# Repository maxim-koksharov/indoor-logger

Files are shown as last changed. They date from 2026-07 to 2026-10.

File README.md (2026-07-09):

# Air Quality Monitor — ESP8266 RTOS SDK

ESP8266-based indoor air quality monitoring system with OLED display, ENS160+AHT21 sensors, WiFi data sync, and a web dashboard.

## System Overview

Two ESP8266 devices communicating over WiFi (both connect to your home router):

```
┌────────────────────┐      WiFi (STA)       ┌────────────────────┐
│   Server (16MB)    │◄─────────────────────►│   Client (4MB)     │
│                    │    Your Home Router   │                    │
│  STA mode          │      192.168.x.x      │  STA mode          │
│  HTTP REST API     │                       │  OLED Display      │
│  Web Dashboard     │                       │  ENS160 + AHT21    │
│  Data Aggregation  │                       │  Local SPIFFS      │
│  UDP discovery     │                       │  WiFi sync         │
│  Backup WiFi       │                       │  UDP discovery     │
│  Timezone config   │                       │  Fallback SERVER_IP│
└────────────────────┘                       └────────────────────┘
```

**WiFi Mode:**
- **Server**: STA-only (connects to your router). Supports primary + backup SSID.
- **Client**: STA-only (connects to the same router). Discovers server via UDP broadcast.

**Server Discovery:** Client sends UDP broadcast to port 5000. Server responds with its IP. No static IP needed.

## Hardware Requirements

- 2× Wemos D1 Mini (ESP8266EX) — 4MB flash for the client, 16MB for the server
- 1× ENS160 + AHT21 air quality sensor module (I2C)
- 1× 0.91" SSD1306 OLED display 128×32 (I2C)
- 1× Tactile button (optional, GPIO12)
- Breadboard and jumper wires

### Wiring

All three I2C devices share a single bus (bus 0):

| Wemos Pin | GPIO | Connection |
|---|---|---|
| D1 | GPIO5 | I2C SCL (OLED + ENS160 + AHT21) |
| D2 | GPIO4 | I2C SDA (OLED + ENS160 + AHT21) |
| D5 | GPIO14 | Output LOW (button GND) |
| D6 | GPIO12 | Input pull-up (button sense) |
| 3V3 | — | VCC (all modules) |
| GND | — | GND (all modules) |

| Device | I2C Address |
|---|---|
| SSD1306 OLED | `0x3C` |
| ENS160 | `0x53` |
| AHT21 | `0x38` |

## Build System

The project uses the standard ESP-IDF CMake build system.
**SDK**: ESP8266 RTOS SDK v3.4 (`/esp/ESP8266_RTOS_SDK`)
**Toolchain**: `/esp/bin/xtensa-lx106-elf/bin`

All commands run inside the Docker container (see `AGENTS.md` for build/run instructions).

### Menuconfig (one-time setup)

```bash
# Client: Client ID, WiFi SSID/pass
idf.py -C apps/client menuconfig

# Server: WiFi SSID/pass (primary + backup)
idf.py -C apps/server menuconfig
```

### Build

```bash
idf.py -C apps/client build
idf.py -C apps/server build
```

### Flash

```bash
idf.py -C apps/client -p /dev/ttyUSB0 flash
idf.py -C apps/server -p /dev/ttyUSB1 flash
```

### Clean

```bash
idf.py -C apps/client fullclean
idf.py -C apps/server fullclean
```

> For the full command list, including monitor and erase, see `AGENTS.md`.

## WiFi Configuration

WiFi SSID and password are read from `/workspace/wifi.env` at build time. Create the file (it is gitignored):

```bash
cat > /workspace/wifi.env <<EOF
WIFI_SSID=MyHomeWiFi
WIFI_PASS=MyPassword
SERVER_IP=192.168.1.100
EOF
```

`SERVER_IP` is optional. It is used by the client as a fallback when UDP broadcast discovery is blocked by the router.

You can still override credentials via `menuconfig` or NVS if needed.

### Server

```bash
idf.py -C apps/server menuconfig
# Server Configuration → Primary WiFi SSID & Password
#                      → Backup WiFi SSID & Password (optional)
idf.py -C apps/server build
idf.py -C apps/server -p /dev/ttyUSB1 flash
```

**Operating mode:**
- The server connects to your router (STA mode)
- Supports a primary and a backup WiFi network (switches after 3 failed attempts)
- Runs a UDP discovery service on port 5000
- The client finds the server automatically via UDP broadcast
- When the network is unreachable → retries connection every 60 sec
- On wrong password → retries every 60 min

**NVS (alternative to menuconfig):**
Credentials can be stored in NVS (survives reflash):
```c
// Via provisioning or a debug script:
nvs_set_str("wifi", "sta_ssid", "YourNetwork");
nvs_set_str("wifi", "sta_pass", "YourPassword");
nvs_commit();
```
NVS takes precedence over menuconfig.

### Client

```bash
idf.py -C apps/client menuconfig
# Client Configuration → Client device identifier
#                      → WiFi SSID (same as server)
#                      → WiFi password (same as server)
idf.py -C apps/client build
idf.py -C apps/client -p /dev/ttyUSB0 flash
```

**Operating mode:**
- The client connects to the same router (STA mode)
- Sends a UDP broadcast on port 5000 to discover the server
- Automatically uses the IP returned by the server for data uploads
- Falls back to `SERVER_IP` from `wifi.env` if broadcast discovery is blocked
- Runs a state machine:
  - `DISCOVERING` — connect to WiFi, discover server
  - `CONNECTED` — upload records, apply server config, sleep for sync interval
  - `AUTONOMOUS` — keep reading sensors locally, retry discovery every hour

### What is `menuconfig` and why do I need it?

`idf.py menuconfig` opens a text-based project configuration UI.
It lets you change build parameters without editing source files:

**WiFi credentials** are read from `wifi.env` at build time. Use `menuconfig` only if you want to override them or store them in the firmware image directly.

**For the client** (`Client Configuration`):
- `Client device identifier` — unique device ID (default `test_client`).
  Used as `?id=<client_id>` when uploading to the server.
- `Display timeout` — auto-off timeout in seconds (0 = always on).
- `Discovery timeout / retry interval / default sync interval` — discovery and sync behavior.

Changes are saved in `sdkconfig` and applied on `idf.py build`.
The config options are exposed in code as `CONFIG_CLIENT_ID`, etc.

**Display:** Off by default. Turns on for 6 seconds on a button press
(2 screens × 3 seconds: temp/time → CO₂/VOC/AQI).

### Serial Monitor

`idf.py monitor` does not work inside Docker (termios error).
Use this Python script instead:

```bash
python3 -c "
import serial, time
ser = serial.Serial('/dev/ttyUSB0', 74880, timeout=1)
ser.dtr = False; ser.rts = True; time.sleep(0.1); ser.rts = False; time.sleep(2)
buf = b''; deadline = time.time() + 10
while time.time() < deadline:
    data = ser.read(4096)
    if data: buf += data
    elif len(buf) > 0: break
ser.close(); print(buf.decode('utf-8', errors='replace'))
"
```

## USB Connection & Serial Debug

Both ESP8266 boards are connected to the host via USB and are passed through to the
container by `docker compose.yml`. All build, flash, and serial debug commands
work **from inside the container** — there is no need to switch to the host shell.

### Device Mapping

| Host device | Board | Used for |
|---|---|---|
| `/dev/ttyUSB0` | Client (Wemos D1 Mini + OLED + ENS160 + AHT21) | Flash, monitor, debug |
| `/dev/ttyUSB1` | Server (Wemos D1 Mini, 16MB flash) | Flash, monitor, debug |

The container is configured with:
- `devices:` passing `/dev/ttyUSB0` and `/dev/ttyUSB1` through
- `device_cgroup_rules: c 188:* rmw` to allow `esptool` / `idf.py` to manage them
- `group_add: ["20"]` (the `dialout` group on the host) so the in-container `dev` user
  can read/write serial ports without `sudo`

### Verifying the connection

Open a shell in the container and check that the devices are visible:

```bash
docker compose run --rm bash

# Inside the container:
ls -l /dev/ttyUSB*
# crw-rw---- 1 root dialout 188, 0 ... /dev/ttyUSB0
# crw-rw---- 1 root dialout 188, 1 ... /dev/ttyUSB1

lsusb
# Bus 001 Device 005: ID 1a86:7523 QinHeng Electronics CH340 serial converter
# ...

# Confirm the in-container user is in dialout:
id
# uid=1000(dev) gid=1000(dev) groups=1000(dev),20(dialout)
```

If `/dev/ttyUSB*` are missing, the host likely does not have permission or the
devices are not enumerated yet:

```bash
# On the host:
ls -l /dev/ttyUSB*              # check device presence
sudo usermod -aG dialout $USER  # add your user to dialout (one-time)
# then log out / log in
```

### Tailing serial output (one-shot, 10s)

Capture the boot log without leaving the container:

```bash
docker compose run --rm bash -c '
  python3 -c "
import serial, time
ser = serial.Serial(\"/dev/ttyUSB0\", 74880, timeout=1)
ser.dtr = False; ser.rts = True; time.sleep(0.1); ser.rts = False; time.sleep(2)
buf = b\"\"; deadline = time.time() + 10
while time.time() < deadline:
    data = ser.read(4096)
    if data: buf += data
    elif len(buf) > 0: break
ser.close(); print(buf.decode(\"utf-8\", errors=\"replace\"))
"
'
```

For the server, replace `/dev/ttyUSB0` with `/dev/ttyUSB1`.

### Continuous log tail (interactive)

For long-running debug sessions, keep the port open and follow output:

```bash
docker compose run --rm bash

# Inside the container:
stty -F /dev/ttyUSB0 74880 raw -echo
cat /dev/ttyUSB0
# press RST on the board to see fresh boot logs
# Ctrl-C to exit
```

### Flashing a board

Flash commands work the same as on the host — just run them from inside the container:

```bash
docker compose run --rm bash

# Inside the container:
cd /workspace/apps/client
idf.py -p /dev/ttyUSB0 flash

cd /workspace/apps/server
idf.py -p /dev/ttyUSB1 flash
```

### Troubleshooting

| Symptom | Likely cause | Fix |
|---|---|---|
| `Could not open /dev/ttyUSB0` | Device busy or not present | Unplug/replug the USB cable; check `lsusb` on the host |
| `Permission denied` on `/dev/ttyUSB*` | User not in `dialout` | `sudo usermod -aG dialout $USER` on the host, then re-login |
| `esptool: failed to connect` | Wrong port or board not in flash mode | Hold `FLASH` button on Wemos D1 Mini during reset, or check wiring |
| Container cannot see `/dev/ttyUSB*` | Device path differs (e.g. `/dev/ttyACM0`) | Edit `compose.yml` `devices:` list and `device_cgroup_rules` (use `c 166:* rmw` for ACM) |
| Garbled serial output | Wrong baud rate | Wemos D1 Mini bootloader prints at **74880 baud**, runtime at **115200** |

## Self-Test

On startup, both applications log a self-test summary.
This is the primary way to verify that everything works:

**Client:**
```
=== SELF-TEST ===
  NVS: OK
  I2C: init OK (SDA=GPIO4 SCL=GPIO5)
  Display: initialized
  ENS160: detected
  AHT21: detected
  SPIFFS: OK (total=... used=...)
  Storage: 125 records saved
  Client ID: living_room
  Heap at init: 64 KB
=== END SELF-TEST ===
```

**Server:**
```
=== SELF-TEST ===
  SPIFFS: OK (total=... used=...)
  NVS: OK
  Registry: 0 clients loaded, 16 slots free
  HTTP: OK
  SNTP: synced
  STA: connected
  STA config: YourNetwork
  Time source: NTP
  Timezone: WET0WEST,M3.5.0/1,M10.5.0/2
  IP: 192.168.1.100
  Heap: 102 KB free
=== END SELF-TEST ===
```

## API Endpoints (Server)

Once connected to the router, the server is reachable on the DHCP-assigned IP (or a static one).
Use the IP directly: `http://192.168.1.100/`

| Method | URI | Description |
|---|---|---|
| GET | `/` | Web dashboard (embedded HTML) |
| GET | `/api/health` | Server status, uptime, free heap |
| GET | `/api/clients` | List all registered clients |
| GET | `/api/client?id=<id>` | Client details + last 24 records |
| POST | `/api/upload?id=<id>` | Upload sensor data JSON. Response includes `timestamp`, `sync_interval`, `name`, `timezone` |
| GET | `/api/data?id=<id>&offset=&limit=` | Query stored records |
| GET | `/api/sync-interval` | Get current sync interval (seconds) |
| POST | `/api/sync-interval?value=<sec>` | Set sync interval (seconds) |
| GET | `/api/timezone` | Get current POSIX timezone string |
| POST | `/api/timezone?value=<tz>` | Set POSIX timezone string |
| GET | `/api/client/name?id=<id>&name=<name>` | Rename a client |

### Upload JSON Format

```json
{
  "readings": [
    {"ts": 1700000000, "up": 1234, "t": 25.5, "h": 55, "c": 400, "v": 100, "a": 1}
  ]
}
```

### Data Storage Format (SPIFFS)

Each client's data is stored in `/spiffs/<client_id>.dat` as a binary ring buffer:

- **Header** (36 bytes): magic, version, client_id, max_records, write_idx, count
- **Records** (14 bytes each): timestamp, temp*100, hum*100, eco2, tvoc, aqi

## Configuration Details

### Client ID

Configured via `menuconfig` → `Client Configuration → Client device identifier`.
Used in `POST /api/upload?id=<client_id>` and as the data filename on the server.

### Server STA Mode

The server connects to your home WiFi (router) to host the HTTP API.
Credentials are set via `menuconfig` (Server Configuration → SERVER_STA_SSID/PASS,
SERVER_BACKUP_SSID/PASS) or stored in NVS (`wifi:sta_ssid`, `wifi:sta_pass`).

**Retry behavior:**
- On network not found → retry every 60 sec
- On auth failure (wrong password) → retry every 60 min
- On other connection errors → retry every 60 sec
- After 3 consecutive `NO_AP_FOUND` events → switch to backup SSID (if configured)

### Timezone

The server uses **Lisbon (WET/WEST)** by default:

```
WET0WEST,M3.5.0/1,M10.5.0/2
```

Change it at runtime from the web dashboard or via the API:

```bash
# Set to UTC
curl -X POST "http://192.168.1.100/api/timezone?value=UTC0"

# Set to Berlin
curl -X POST "http://192.168.1.100/api/timezone?value=CET-1CEST,M3.5.0/2,M10.5.0/3"
```

Common POSIX timezone strings:

| Location | POSIX TZ string |
|---|---|
| Lisbon (default) | `WET0WEST,M3.5.0/1,M10.5.0/2` |
| UTC | `UTC0` |
| London | `GMT0BST,M3.5.0/1,M10.5.0/2` |
| Berlin / Paris / Madrid / Rome | `CET-1CEST,M3.5.0/2,M10.5.0/3` |
| New York / Miami / Atlanta | `EST5EDT,M3.2.0/2,M11.1.0/2` |
| Chicago / Houston | `CST6CDT,M3.2.0/2,M11.1.0/2` |
| Denver / Salt Lake City | `MST7MDT,M3.2.0/2,M11.1.0/2` |
| Los Angeles / Seattle | `PST8PDT,M3.2.0/2,M11.1.0/2` |
| Moscow | `MSK-3` |
| Tokyo / Osaka | `JST-9` |
| Beijing / Shanghai / Hong Kong | `CST-8` |
| Singapore | `SGT-8` |
| Seoul | `KST-9` |
| Bangkok / Jakarta | `ICT-7` |
| Dubai / Abu Dhabi | `GST-4` |
| India (Mumbai / Delhi) | `IST-5:30` |
| Sydney (with DST) | `AEDT-10AEST,M10.1.0/2,M4.1.0/3` |
| Auckland (with DST) | `NZDT-12NZST,M9.5.0/2,M4.1.0/3` |
| São Paulo | `BRT3` |
| Buenos Aires | `ART3` |
| Cairo | `EET-2EEST,M4.last.4/24,M10.last.4/24` |
| Jerusalem | `IST-2IDT,M3.4.4/26,M10.5.0` |
| South Africa (Johannesburg) | `SAST-2` |
| Turkey (Istanbul) | `TRT-3` |

The timezone is stored in NVS and pushed to the client on every upload, so both devices display the same local time.

### ENS160

ENS160 requires ~3 minutes of warm-up for the first reading and ~1 hour to stabilize.
To disable ENS160 at compile time:

```c
#define ENS160_ENABLE 0
#include "ens160.h"
```

## Known ESP8266 Limitations

- **`%f` in printf/snprintf**: Not supported without `CONFIG_NEWLIB_STDOUT_FLOATING_POINT` (+28 KB). Use integer arithmetic: `(int)(val * 10) % 10`.
- **`vTaskDelay()` in `app_main()`**: Causes `rst cause: 2`. Use `xTaskCreate()` for main loops.
- **`esp_event_loop_create_default()`**: Only call once. Crashes on second call.
- **`esp_task_wdt_add()`**: Not available in v3.4. Use `esp_task_wdt_reset()` in each loop.
- **`httpd_resp_send_err()`**: Not available in v3.4. Use `httpd_resp_send_404()`/`httpd_resp_send_500()` or manually set type+send.
- **HTTP server URI wildcards**: ESP-IDF v3.4 does exact `strncmp` matching only. No `*` wildcard support. Use exact paths with query parameters.
- **mDNS not available on ESP8266**: mdns.h references `ip6_addr_t` which is not defined. Use UDP broadcast discovery (port 5000) instead.
- **WiFi retry behavior**:
  - Network not found (reason 201) → retry after 60 seconds
  - Wrong password (reason 2, 4, 204) → retry after 3600 seconds (1 hour)
  - Other disconnect reasons → retry after 60 seconds
  - After 3 consecutive NO_AP_FOUND → automatically switch to backup SSID

## Components

| Component | Description |
|---|---|
| `components/display/` | C wrapper for SSD1306 OLED driver (128×32, I2C) |
| `components/sensors/` | ENS160 (eCO₂, TVOC, AQI) + AHT21 (T, RH) I2C drivers |
| `components/fonts/` | Bitmap font library (GLCD 5x7, Terminus, Roboto, Bitocra) |
| `components/wifi/` | WiFi manager for STA-only with retry logic |

## Data Flow

```
Client                             Server
──────                             ──────
ENS160 + AHT21 → sensor_read()
        │
        ▼
data_storage_append()  ← SPIFFS ring buffer
        │
        ▼ (every sync interval, default 600s, via router)
UDP broadcast → port 5000 → discovery
        │
        ▼
wifi_sync_upload()  ─── POST /api/upload?id=<id> ──→  data_store_append()
                                                          │
                                                          ▼
                                                     SPIFFS per-client .dat
                                                          │
                                                     Web UI (GET /)
```

**Discovery Protocol:**
1. Client sends `AIRMON_DISCOVER` to UDP broadcast:5000
2. Server responds with `AIRMON_RESPONSE <ip>`
3. Client caches the IP and uses it for all upload requests
4. If broadcast is blocked, client falls back to `SERVER_IP` from `wifi.env`
5. On upload error → rediscovery on the next sync cycle

**Server Config Push:**
Each upload response includes the current `timestamp`, `sync_interval`, `name`, and `timezone`. The client applies these immediately:
- System time is set from the server timestamp
- Sync interval is updated (default 600 s, configurable via web UI/API)
- Assigned name is shown briefly on the OLED and used in the web UI
- Timezone is applied so the OLED clock matches the server

## Project Structure

```
├── cmake/                    # CMake helpers
│   └── wifi_config.cmake     # Loads wifi.env at build time
├── components/               # Shared IDF-style components
│   ├── display/              # SSD1306 OLED driver + C wrapper
│   ├── sensors/              # ENS160 + AHT21 I2C drivers
│   ├── fonts/                # Bitmap font library
│   └── wifi/                 # WiFi manager (STA-only with retry logic)
├── apps/
│   ├── server/               # Server firmware (16MB flash)
│   │   └── main/             # main.c, data_store.c, client_registry.c, http_server.c
│   └── client/               # Client firmware (4MB flash)
│       ├── main/             # main.c, data_storage.c, wifi_sync.c, button.c
│       └── partitions_client.csv
├── wifi.env                  # WiFi credentials (gitignored)
├── README.md
├── AGENTS.md
└── TODO.md
```

## License

Project code: MIT. Third-party components have their own licenses.

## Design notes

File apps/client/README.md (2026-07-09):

# Client Application — 4MB ESP8266

OLED display, sensor readings, local data storage, and WiFi sync to server.

## Hardware

| Requirement | Detail |
|---|---|
| Board | Wemos D1 Mini (4MB flash) |
| Sensors | ENS160 (I2C, addr 0x53) + AHT21 (I2C, addr 0x38) |
| Display | SSD1306 OLED 128×32 (I2C, addr 0x3C) |
| Button | GPIO12 (optional, tactile switch to GND) |
| Serial | `/dev/ttyUSB0` |

## Partition Table

| Partition | Offset | Size |
|---|---|---|
| nvs | 0x9000 | 16 KB |
| phy_init | 0xF000 | 4 KB |
| factory | 0x10000 | 1 MB |
| spiffs | 0x110000 | ~3 MB |

## Build & Flash

```bash
cd apps/client

# Configure (optional — changes client_id, display timeout)
idf.py menuconfig
  → Client Configuration
    → Client device identifier  (CONFIG_CLIENT_ID, default: test_client)
    → Display auto-off timeout  (CONFIG_CLIENT_DISPLAY_TIMEOUT_SEC, default: 10)

# Build
idf.py build

# Flash
idf.py -p /dev/ttyUSB0 flash
```

**Important**: `CONFIG_CLIENT_ID` is the unique client identifier (e.g. `living_room`, `kitchen`).
If left unchanged, it defaults to `test_client`.

## Feature Summary

| Feature | Details |
|---|---|
| Sensors | ENS160 (eCO₂, TVOC, AQI) + AHT21 (temp, humidity) |
| Display | SSD1306 128×32, scaled text, updates every 5s |
| Storage | Local ring buffer in SPIFFS (5000 records max) |
| WiFi Sync | Connects to server AP, uploads JSON every 30s |
| Architecture | FreeRTOS task (`client_task`, 4KB stack) for main loop |

## Client ID

Configured via `menuconfig` → `Client Configuration → Client device identifier`.
The ID is passed as the `?id=<id>` query parameter on every upload.
On the server, the data is stored in the file `/spiffs/<id>.dat`.

## ENS160 Configuration

ENS160 requires ~3 minutes for first valid reading. To compile without ENS160:

```c
#define ENS160_ENABLE 0
#include "ens160.h"
```

When disabled, only AHT21 temperature/humidity is reported. Display shows "ENS warming..." and eCO₂/TVOC/AQI values are zero.

## Display Pages

The display shows two lines updated every 5 seconds:

```
26.5C 52% AQI1       ← temp, humidity, AQI
eCO2 400 TVOC 12     ← ENS160 readings
```

If ENS160 is warming up or disabled:
```
26.5C 52%             ← temp, humidity only
ENS warming...        ← placeholder
```

## Data Flow

```
Every 5 seconds:
  ENS160 + AHT21 → read sensors
                → save to SPIFFS (client_record_t)
                → update display

Every 30 seconds:
  Connect to AirMon-Server
  Read 5 unsynced records from SPIFFS
  POST JSON to http://192.168.4.1/api/upload?id=<client_id>
  Mark records synced on 200 OK
```

## Components Used

- `components/display` — SSD1306 OLED driver + Display wrapper
- `components/sensors` — ENS160 + AHT21 sensor drivers
- `components/fonts` — Bitmap font library (GLCD 5x7)
- `components/wifi` — WiFi manager (STA mode only)
- ESP-IDF: `nvs_flash`, `spiffs`, `esp_http_client`, `driver/i2c`

## Self-Test at Startup

The client logs a self-test summary after all components are initialized:

```
=== SELF-TEST ===
  NVS: OK
  I2C: init OK (SDA=GPIO4 SCL=GPIO5)
  Display: initialized
  ENS160: detected          (or "warming" / "disabled")
  AHT21: detected           (or "failed")
  SPIFFS: OK (total=1048576 used=16384)
  Storage: 125 records saved
  Client ID: living_room
  Heap at init: 64 KB
=== END SELF-TEST ===
```

## Known Limitations

- `time(NULL)` returns 0 (no RTC/NTP); uptime_sec used as timestamp
- Deep sleep not yet implemented (currently always-on for debugging)
- `%f` does not work in ESP8266 printf; all float display uses integer math

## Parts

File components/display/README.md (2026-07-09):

# Display — SSD1306 OLED Driver

C wrapper for the SSD1306 OLED display (128×32, I2C) with a convenient high-level API.

## Files

| File | Description |
|---|---|
| `ssd1306.c` / `include/ssd1306.h` | Low-level SSD1306 I2C driver (third-party, MIT licensed) |
| `Display.c` / `include/Display.h` | High-level C wrapper with framebuffer and scaled text |

## Dependencies

- `driver/i2c` (ESP-IDF)
- `components/fonts` (bitmap fonts)

## Features

- 128×32 pixel monochrome display at I2C address `0x3C`
- 512-byte framebuffer (`128 × 32 / 8`)
- Scaled text rendering (2x for readability on small display)
- Framebuffer-based drawing (pixel, line, rectangle, fill)
- Init sequence, on/off, contrast, inversion control

## Usage

```c
#include "Display.h"

Display display;

display_init(&display, GPIO4, GPIO5, SSD1306_I2C_ADDR_0);  // SDA=D2, SCL=D1

const font_info_t *font = font_builtin_fonts[FONT_FACE_GLCD5x7];
display_clear_fb(&display);
display_draw_string_scaled(&display, font, 0, 0, "Hello", 2);
display_present(&display);
display_on(&display);
```

## API

| Function | Purpose |
|---|---|
| `display_init()` | Initialize I2C, configure SSD1306, create framebuffer |
| `display_on()` / `display_off()` | Display power control |
| `display_clear_fb()` | Clear framebuffer (in RAM, not sent to display) |
| `display_present()` | Send framebuffer to display via I2C |
| `display_draw_pixel()` | Set individual pixel |
| `display_draw_hline()` / `display_draw_vline()` | Horizontal/vertical line |
| `display_draw_char_scaled()` | Single character with scale factor |
| `display_draw_string_scaled()` | String with scale factor |

## Important Notes

- The display is physically **128×32**, not 128×64. Pixels with `y >= 32` are invisible.
- GLCD 5×7 font at 1× is too small. Use 2× scaling: `display_draw_string_scaled(&d, font, x, y, "text", 2)`.
- At 2× scaling, ~10 characters per line, ~2 lines fit on the display.

## License

SSD1306 driver: MIT (by urx, UncleRus, Zaltora). See `ssd1306.h` header.

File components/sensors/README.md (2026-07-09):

# Sensors — ENS160 + AHT21 I2C Drivers

I2C sensor drivers for the ENS160 air quality sensor and AHT21 temperature/humidity sensor.

## Files

| File | Description |
|---|---|
| `ens160.c` / `include/ens160.h` | ENS160 driver (eCO₂, TVOC, AQI) |
| `aht21.c` / `include/aht21.h` | AHT21 driver (temperature, humidity) |

## Dependencies

- `driver/i2c` (ESP-IDF)

## ENS160 — Air Quality Sensor

| Property | Value |
|---|---|
| I2C address | `0x53` |
| Measurements | eCO₂ (ppm), TVOC (ppb), AQI (1–5) |
| Warm-up | ~3 minutes for first reading |
| Stabilization | ~1 hour nominal, 48 hours for best accuracy |
| Operating mode | `0x02` (STANDARD) — must NOT be `0x01` (IDLE) |

### ENS160_ENABLE

Compile out ENS160 support to save code size or when only AHT21 is needed:

```c
#define ENS160_ENABLE 0
#include "ens160.h"
```

Default is 1 (enabled).

## AHT21 — Temperature & Humidity

| Property | Value |
|---|---|
| I2C address | `0x38` |
| Measurements | Temperature (°C), humidity (% RH) |
| Accuracy | ±0.3 °C, ±2% RH |

## Usage

```c
#include "ens160.h"
#include "aht21.h"

// Init (in app_main)
ens160_init(I2C_NUM_0);
aht21_init(I2C_NUM_0);

// Read every 5 seconds
aht21_data_t aht = {0};
ens160_data_t ens = {0};

int aht_ret = aht21_read(I2C_NUM_0, &aht);
if (aht_ret == 0) {
    // aht.temperature, aht.humidity
}

int ens_ret = ens160_read(I2C_NUM_0, &ens);
if (ens_ret == 0) {
    // ens.eco2, ens.tvoc, ens.aqi
}

// Feed temperature/humidity to ENS160 for compensation
ens160_set_env(I2C_NUM_0, aht.temperature, aht.humidity);
```

## ENS160 Status Codes

| Return | Meaning |
|---|---|
| `0` | Success, new data valid |
| `-1` | I2C communication error |
| `-2` | No new data ready (retry after 50–100 ms) |

## ESP8266 Note

Do NOT use `%f` in `printf`/`ESP_LOGI` when printing sensor values. Use integer arithmetic:
```c
int t_int = (int)temperature;
int t_dec = (int)(temperature * 10) % 10;
ESP_LOGI(TAG, "T=%d.%d", t_int, t_dec);
```

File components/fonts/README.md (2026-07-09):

# Fonts — Bitmap Font Library

Compile-time bitmap font library for small OLED/LCD displays. Derived from the esp-open-rtos font project.

## Files

| File | Description |
|---|---|
| `fonts.c` / `fonts.h` | Font access API and built-in font registry |
| `data/` | Binary font data (embedded at compile time) |
| `tools/` | Font generation tools |
| `LICENSE` / `OFL.txt` | License files |

## Available Fonts

| Enum | Name | Char Range |
|---|---|---|
| `FONT_FACE_GLCD5x7` | GLCD 5×7 | 0–255 |
| `FONT_FACE_ROBOTO_8PT` | Roboto 8pt | — |
| `FONT_FACE_ROBOTO_10PT` | Roboto 10pt | — |
| `FONT_FACE_BITOCRA_4X7` | Bitocra 4×7 | — |
| `FONT_FACE_BITOCRA_6X11` | Bitocra 6×11 | — |
| `FONT_FACE_BITOCRA_7X13` | Bitocra 7×13 | — |
| `FONT_FACE_TERMINUS_*` | Terminus (various sizes) | ISO8859-1 |
| `FONT_FACE_COMPACT_6X8` | Compact 6×8 | 0x20–0xFF |
| `FONT_FACE_ROBOTO_12PT` | Roboto 12pt | — |
| `FONT_FACE_ROBOTO_16PT` | Roboto 16pt | — |

## Usage

```c
#include "fonts.h"

const font_info_t *font = font_builtin_fonts[FONT_FACE_GLCD5x7];
```

## Recommendation

For 128×32 OLED at 2× scaling, use `FONT_FACE_GLCD5x7` — it's the smallest and most reliable. At 2×, each character is ~10×14 pixels, fitting ~2 lines of 12 characters.

## License

Dual-licensed: OFL-1.1 for Terminus fonts, MIT for the library code.

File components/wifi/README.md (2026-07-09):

# WiFi Manager

ESP8266 WiFi connection helper supporting Station (STA), Access Point (AP), and AP+STA fallback modes.

## Files

| File | Description |
|---|---|
| `wifi_manager.c` / `include/wifi_manager.h` | WiFi mode management |

## Dependencies

- `esp_wifi` (ESP-IDF)
- `esp_event` (ESP-IDF)
- `tcpip_adapter` (ESP-IDF)
- `nvs_flash` (ESP-IDF)

## Modes

| Function | Mode | Description |
|---|---|---|
| `wifi_manager_init_sta()` | STA | Connect to an existing WiFi network |
| `wifi_manager_init_ap()` | AP | Create a WiFi access point |
| `wifi_manager_init_ap_with_sta_fallback()` | APSTA → AP | Try STA first; if it fails, fall back to AP-only |

## Usage

```c
#include "wifi_manager.h"

// AP only
wifi_manager_init_ap("MyAP", "password");

// STA only
wifi_manager_init_sta("HomeWiFi", "password");

// AP with STA fallback (tries STA for 30s, falls back to AP)
wifi_manager_init_ap_with_sta_fallback(
    "AirMon-Server", "ap_password",
    "HomeWiFi", "home_password",
    30);

// Check connection
bool connected = wifi_manager_is_connected();

// Get IPs
char ip[16];
wifi_manager_get_ip(ip, sizeof(ip));       // STA IP
wifi_manager_get_ap_ip(ip, sizeof(ip));    // AP IP
```

## Important Notes

- `esp_event_loop_create_default()` is called internally by each init function. **Calling init twice crashes** (`ESP_ERR_INVALID_STATE` → abort). Use `wifi_manager_init_ap_with_sta_fallback()` instead of calling multiple init functions.
- STA auto-reconnects on disconnect (event handler calls `esp_wifi_connect()`).
- AP is always `AirMon-Server` on channel 1, max 4 connections.

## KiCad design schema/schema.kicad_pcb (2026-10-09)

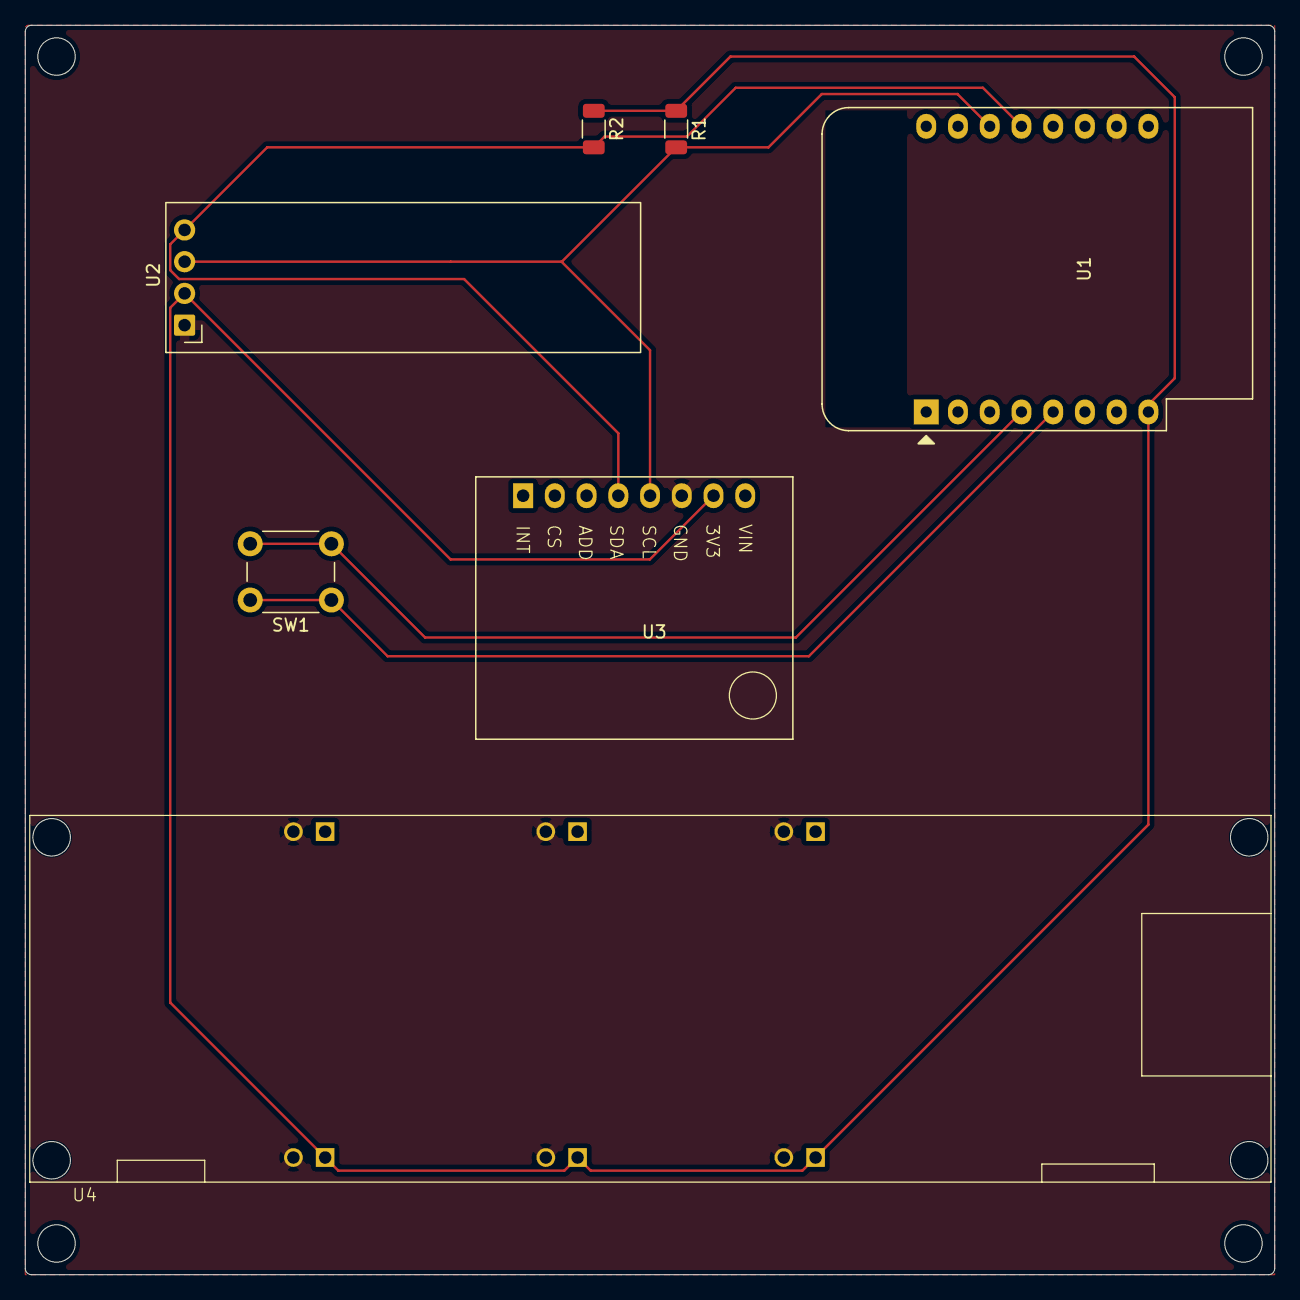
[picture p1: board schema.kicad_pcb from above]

Board: 2 copper layers, 100.0 x 100.0 mm, 7 parts (0 on the bottom side), 6 nets.

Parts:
R1, R2: 5.1K; R_1206_3216Metric
SW1: SW_Push; SW_PUSH_6mm_H5mm
U1: WEMOS_D1_mini; WEMOS_D1_mini_light
U2: ER_OLEDM0.91_1x-I2C
U3: ENS160+AHT21
U4: 18650 Battery Shield v3

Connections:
+3.3V: R1.1, R2.1, U1.8 (3V3), U2.2 (VCC), U3.7 (3V3), U4.1 (3V)
/SCL: R1.2, U1.14 (SCL/D1), U2.3 (SCL), U3.5 (SCL/SCLK)
/SDA: R2.2, U1.13 (SDA/D2), U2.4 (SDA), U3.4 (SDA/MOSI)
/button_in: SW1.1, U1.5 (MISO/D6)
/button_out: SW1.2, U1.4 (SCK/D5)
GND: U1.10 (GND), U2.1 (GND), U3.6 (GND), U4.2 (GND)

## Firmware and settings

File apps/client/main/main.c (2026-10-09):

#include "Display.h"
#include "ens160.h"
#include "aht21.h"
#include "button.h"
#include "data_storage.h"
#include "wifi_sync.h"
#include "wifi_manager.h"
#include <stdio.h>
#include <string.h>
#include <time.h>
#include <sys/time.h>
#include "freertos/FreeRTOS.h"
#include "freertos/task.h"
#include "esp_log.h"
#include "esp_system.h"
#include "esp_wifi.h"
#include "driver/i2c.h"
#include "driver/gpio.h"
#include "nvs_flash.h"
#include "esp_task_wdt.h"
#include "esp_spiffs.h"
#include "esp_sleep.h"

static const char *TAG = "client";

#define SDA_PIN 4
#define SCL_PIN 5

#define SENSOR_READ_INTERVAL_MS 300000
#define WIFI_SYNC_INTERVAL_MS 300000
#define DISPLAY_ON_MS 12000
#define DISPLAY_SCREEN_INTERVAL_MS 4000

#ifndef CONFIG_CLIENT_ID
#define CONFIG_CLIENT_ID "test_client"
#endif

#ifndef CONFIG_CLIENT_DISPLAY_TIMEOUT_SEC
#define CONFIG_CLIENT_DISPLAY_TIMEOUT_SEC 10
#endif

#ifndef CONFIG_CLIENT_WIFI_SSID
#define CONFIG_CLIENT_WIFI_SSID ""
#endif

#ifndef CONFIG_CLIENT_WIFI_PASS
#define CONFIG_CLIENT_WIFI_PASS ""
#endif

/* Priority: wifi.env compile definitions > Kconfig defaults */
#ifdef WIFI_SSID
#define CLIENT_WIFI_SSID WIFI_SSID
#else
#define CLIENT_WIFI_SSID CONFIG_CLIENT_WIFI_SSID
#endif

#ifdef WIFI_PASS
#define CLIENT_WIFI_PASS WIFI_PASS
#else
#define CLIENT_WIFI_PASS CONFIG_CLIENT_WIFI_PASS
#endif

#ifndef CONFIG_CLIENT_DISCOVER_TIMEOUT_MS
#define CONFIG_CLIENT_DISCOVER_TIMEOUT_MS 3000
#endif

#ifndef CONFIG_CLIENT_BACKUP_SSID
#define CONFIG_CLIENT_BACKUP_SSID ""
#endif

#ifndef CONFIG_CLIENT_BACKUP_PASS
#define CONFIG_CLIENT_BACKUP_PASS ""
#endif

/* Secondary SSID/pass. Priority: wifi.env (WIFI_SSID_2 / WIFI_PASS_2) >
 * Kconfig backup (CONFIG_CLIENT_BACKUP_SSID / CONFIG_CLIENT_BACKUP_PASS). */
#ifdef WIFI_SSID_2
#define CLIENT_WIFI_SSID_2 WIFI_SSID_2
#else
#define CLIENT_WIFI_SSID_2 CONFIG_CLIENT_BACKUP_SSID
#endif

#ifdef WIFI_PASS_2
#define CLIENT_WIFI_PASS_2 WIFI_PASS_2
#else
#define CLIENT_WIFI_PASS_2 CONFIG_CLIENT_BACKUP_PASS
#endif

#ifndef CONFIG_CLIENT_RETRY_INTERVAL_MS
#define CONFIG_CLIENT_RETRY_INTERVAL_MS 3600000
#endif

#ifndef CONFIG_CLIENT_DEFAULT_SYNC_INTERVAL_SEC
#define CONFIG_CLIENT_DEFAULT_SYNC_INTERVAL_SEC 600
#endif

static const char *reset_reason_to_str(esp_reset_reason_t reason) {
    switch (reason) {
        case ESP_RST_POWERON:   return "POWERON";
        case ESP_RST_EXT:       return "EXT";
        case ESP_RST_SW:        return "SW";
        case ESP_RST_PANIC:     return "PANIC";
        case ESP_RST_INT_WDT:   return "INT_WDT";
        case ESP_RST_TASK_WDT:  return "TASK_WDT";
        case ESP_RST_WDT:       return "WDT";
        case ESP_RST_DEEPSLEEP: return "DEEPSLEEP";
        case ESP_RST_BROWNOUT:  return "BROWNOUT";
        case ESP_RST_SDIO:      return "SDIO";
        default:                return "UNKNOWN";
    }
}

static Display display;
static const font_info_t *display_font = NULL;
static TaskHandle_t client_task_handle = NULL;

static aht21_data_t last_aht_data = {0};

/* Client connection states. */
typedef enum {
    STATE_DISCOVERING,
    STATE_CONNECTED,
    STATE_AUTONOMOUS
} client_state_t;
static ens160_data_t last_ens_data = {0};

static uint32_t client_uptime_sec = 0;
static int display_screen = 0;
static uint32_t s_planned_sleep_ms = 0;
static bool s_wifi_initialized = false;
static TickType_t s_id_display_until = 0;
static char s_id_display_str[32] = {0};

static void update_display(void) {
    TickType_t now_tick = xTaskGetTickCount();
    if (s_id_display_until != 0 && now_tick < s_id_display_until) {
        display_clear_fb(&display);
        int scale = 3;
        int len = strlen(s_id_display_str);
        if (len * 6 * scale > 128) scale = 2;
        if (len * 6 * scale > 128) scale = 1;
        int char_w = 6 * scale;
        int text_w = len * char_w;
        int x = (128 - text_w) / 2;
        if (x < 0) x = 0;
        int y = (32 - 7 * scale) / 2;
        display_draw_string_scaled(&display, display_font, x, y, s_id_display_str, scale);
        display_present(&display);
        return;
    }
    if (s_id_display_until != 0 && now_tick >= s_id_display_until) {
        s_id_display_until = 0;
        s_id_display_str[0] = '\0';
    }

    display_clear_fb(&display);

    int t_int = (int)last_aht_data.temperature;
    int t_dec = (int)(last_aht_data.temperature * 10) % 10;
    if (t_dec < 0) t_dec = -t_dec;

    bool basic_mode = wifi_sync_is_basic_mode();

    if (display_screen == 0) {
        char line1[16], line2[16];
        snprintf(line1, sizeof(line1), "%d.%dC %d%%", t_int, t_dec, (int)last_aht_data.humidity);
        time_t now = time(NULL);
        if (now > 0) {
            struct tm ti;
            localtime_r(&now, &ti);
            snprintf(line2, sizeof(line2), "%02d:%02d:%02d", ti.tm_hour, ti.tm_min, ti.tm_sec);
        } else {
            snprintf(line2, sizeof(line2), "--:--:--");
        }
        int w1 = strlen(line1) * 12;
        int w2 = strlen(line2) * 12;
        display_draw_string_scaled(&display, display_font, (128 - w1) / 2, 0, line1, 2);
        display_draw_string_scaled(&display, display_font, (128 - w2) / 2, 17, line2, 2);
    } else if (display_screen == 1) {
        if (basic_mode) {
            const char *name = wifi_sync_get_assigned_name();
            const char *display_name = (name && name[0]) ? name : "not_defined";
            int char_w = 12;
            int w = strlen(display_name) * char_w;
            int x = (w > 128) ? 0 : (128 - w) / 2;
            display_draw_string_scaled(&display, display_font, x, 10, display_name, 2);
        } else {
            char line1[16], line2[16];
            snprintf(line1, sizeof(line1), "CO2 %u", last_ens_data.eco2);
            snprintf(line2, sizeof(line2), "VOC %u A%u", last_ens_data.tvoc, last_ens_data.aqi);
            display_draw_string_scaled(&display, display_font, 0, 0, line1, 2);
            display_draw_string_scaled(&display, display_font, 0, 17, line2, 2);
        }
    } else {
        const char *name = wifi_sync_get_assigned_name();
        const char *display_name = (name && name[0]) ? name : "not_defined";
        int char_w = 12;
        int w = strlen(display_name) * char_w;
        int x = (w > 128) ? 0 : (128 - w) / 2;
        display_draw_string_scaled(&display, display_font, x, 10, display_name, 2);
    }
    display_present(&display);
}

static void client_adjust_time_after_sleep(uint32_t sleep_ms) {
    if (sleep_ms == 0) return;
    struct timeval tv;
    if (gettimeofday(&tv, NULL) != 0) {
        return;
    }
    uint32_t add_sec = sleep_ms / 1000;
    uint32_t add_usec = (sleep_ms % 1000) * 1000;
    tv.tv_usec += add_usec;
    if ((uint32_t)tv.tv_usec >= 1000000) {
        tv.tv_sec++;
        tv.tv_usec -= 1000000;
    }
    tv.tv_sec += add_sec;
    settimeofday(&tv, NULL);
    ESP_LOGI(TAG, "[TIME] Adjusted by %u ms (was %lu, now %lu)",
             sleep_ms, (unsigned long)(tv.tv_sec - add_sec), (unsigned long)tv.tv_sec);
}

static void client_sync_time_with_server(void) {
    if (!wifi_manager_is_connected()) return;
    uint32_t ts = 0;
    esp_err_t ret = wifi_sync_get_server_time(&ts);
    if (ret == ESP_OK && ts > 0) {
        struct timeval tv = { .tv_sec = (time_t)ts, .tv_usec = 0 };
        settimeofday(&tv, NULL);
        ESP_LOGI(TAG, "[TIME] Synced from server: %lu", (unsigned long)ts);
    } else {
        ESP_LOGW(TAG, "[TIME] Server time sync failed: %d", ret);
    }
}

static void client_show_sensor_error(void) {
    display_clear_fb(&display);
    display_draw_string_scaled(&display, display_font, 16, 0, "SENSOR", 2);
    display_draw_string_scaled(&display, display_font, 28, 17, "ERROR", 2);
    display_present(&display);
    display_on(&display);
}

static bool read_sensors_and_store(void) {
    ESP_LOGI(TAG, "[SENSORS] Reading...");

    aht21_data_t aht_data = {0};
    ens160_data_t ens_data = {0};
    bool basic_mode = wifi_sync_is_basic_mode();
    bool aht_ok = false;
    bool ens_ok = false;

    int aht_ret = aht21_read(I2C_NUM_0, &aht_data);
    esp_task_wdt_reset();
    if (aht_ret == 0) {
        last_aht_data = aht_data;
        aht_ok = true;
        int t_int = (int)aht_data.temperature;
        int t_dec = (int)(aht_data.temperature * 10) % 10;
        if (t_dec < 0) t_dec = -t_dec;
        ESP_LOGI(TAG, "[SENSORS] AHT21: T=%d.%d H=%d", t_int, t_dec, (int)aht_data.humidity);
    } else {
        ESP_LOGW(TAG, "[SENSORS] AHT21 failed: %d", aht_ret);
    }

#if ENS160_ENABLE
    if (basic_mode) {
        last_ens_data = (ens160_data_t){0};
        ESP_LOGI(TAG, "[SENSORS] ENS160 skipped (basic_mode)");
    } else {
        int ens_ret = ens160_read(I2C_NUM_0, &ens_data);
        esp_task_wdt_reset();
        if (ens_ret == 0) {
            last_ens_data = ens_data;
            ens_ok = true;
            ESP_LOGI(TAG, "[SENSORS] ENS160: eCO2=%u TVOC=%u AQI=%u", ens_data.eco2, ens_data.tvoc, ens_data.aqi);
        } else {
            ESP_LOGW(TAG, "[SENSORS] ENS160 failed: %d", ens_ret);
        }

        ens160_set_env(I2C_NUM_0, last_aht_data.temperature, last_aht_data.humidity);
        esp_task_wdt_reset();
    }
#else
    (void)ens_data;
    ESP_LOGI(TAG, "[SENSORS] ENS160 disabled");
#endif

    client_uptime_sec = (uint32_t)(xTaskGetTickCount() * portTICK_PERIOD_MS / 1000);

    time_t now_ts = time(NULL);
    if (now_ts <= 0) {
        now_ts = (time_t)client_uptime_sec;
    }

    client_record_t record = {
        .timestamp = now_ts,
        .uptime_sec = client_uptime_sec,
        .temperature = last_aht_data.temperature,
        .humidity = last_aht_data.humidity,
        .eco2 = last_ens_data.eco2,
        .tvoc = last_ens_data.tvoc,
        .aqi = last_ens_data.aqi,
        .synced = false
    };

    if (data_storage_append(&record) == 0) {
        ESP_LOGI(TAG, "[STORAGE] Saved ts=%ld up=%u, total=%d",
                 (long)record.timestamp, record.uptime_sec,
                 data_storage_get_count());
    } else {
        ESP_LOGW(TAG, "[STORAGE] Append failed, SPIFFS may be full");
    }

    if (basic_mode) {
        return aht_ok;
    }
    return aht_ok && ens_ok;
}

static esp_err_t client_ensure_wifi_connected(void) {
    if (wifi_manager_is_connected()) {
        return ESP_OK;
    }
    ESP_LOGI(TAG, "[WIFI] Starting for upload");
    esp_err_t ret = esp_wifi_start();
    if (ret != ESP_OK) {
        ESP_LOGW(TAG, "[WIFI] esp_wifi_start() failed: %d", ret);
    }
    int retry = 0;
    while (!wifi_manager_is_connected() && retry < 30) {
        vTaskDelay(pdMS_TO_TICKS(1000));
        esp_task_wdt_reset();
        retry++;
    }
    return wifi_manager_is_connected() ? ESP_OK : ESP_ERR_TIMEOUT;
}

static esp_err_t client_bootstrap_wifi(void) {
    if (s_wifi_initialized && wifi_manager_is_connected() && wifi_sync_get_server_ip() != NULL) {
        return ESP_OK;
    }
    ESP_LOGI(TAG, "[WIFI] Bootstrapping connection for cycle");
    esp_err_t ret = wifi_sync_connect_to_server(CLIENT_WIFI_SSID, CLIENT_WIFI_PASS,
                                                CLIENT_WIFI_SSID_2, CLIENT_WIFI_PASS_2);
    s_wifi_initialized = (ret == ESP_OK);
    return ret;
}

static esp_err_t client_perform_upload_cycle(bool from_button);

static void client_check_id_change_and_show(void) {
    char new_id[32];
    if (!wifi_sync_take_id_change(new_id, sizeof(new_id))) return;
    ESP_LOGI(TAG, "[ID] New client ID received: %s, showing on display for 5 sec", new_id);
    strncpy(s_id_display_str, new_id, sizeof(s_id_display_str) - 1);
    s_id_display_str[sizeof(s_id_display_str) - 1] = '\0';
    s_id_display_until = xTaskGetTickCount() + pdMS_TO_TICKS(5000);
    display_clear_fb(&display);
    display_present(&display);
    display_on(&display);
    update_display();
}

static void client_turn_off_wifi_and_reset_state(TickType_t now) {
    /* For light sleep on ESP8266, esp_wifi_get_state() must be < WIFI_STATE_START.
     * esp_wifi_stop() leaves state in INIT. We intentionally do NOT call
     * esp_wifi_deinit() here — deinit moves the state to WIFI_STATE_DEINIT and
     * forces the next wifi_manager_init_sta_dual() to re-run init_wifi_subsystem(),
     * which would re-invoke esp_event_loop_create_default() / tcpip_adapter_init()
     * and trigger abort() (these can only be initialised once per boot).
     * Leaving state in INIT lets the next init reuse the existing subsystem. */
    if (esp_wifi_get_state() >= WIFI_STATE_START) {
        esp_err_t stop_ret = esp_wifi_stop();
        if (stop_ret != ESP_OK) {
            ESP_LOGW(TAG, "[WIFI] esp_wifi_stop() failed: %d", stop_ret);
        }
        int wait = 0;
        while (esp_wifi_get_state() >= WIFI_STATE_START && wait < 50) {
            vTaskDelay(pdMS_TO_TICKS(20));
            wait++;
        }
    }
    (void)now;
}

static esp_err_t client_perform_upload_cycle(bool from_button) {
    esp_err_t ret = client_bootstrap_wifi();
    if (ret != ESP_OK) {
        ESP_LOGW(TAG, "[CYCLE] WiFi bootstrap failed");
        return ret;
    }
    if (!wifi_manager_is_connected()) {
        ret = client_ensure_wifi_connected();
        if (ret != ESP_OK) {
            ESP_LOGW(TAG, "[CYCLE] WiFi not available");
            return ret;
        }
    }
    client_sync_time_with_server();
    ret = wifi_sync_upload_unsynced();
    if (ret == ESP_OK) {
        ESP_LOGI(TAG, "[CYCLE] Upload OK");
    } else {
        ESP_LOGW(TAG, "[CYCLE] Upload failed: %d", ret);
    }
    client_check_id_change_and_show();
    return ret;
}
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
void app_main(void) {
    ESP_LOGI(TAG, "Client starting...");
    esp_reset_reason_t reason = esp_reset_reason();
    ESP_LOGI(TAG, "Reset reason: %s (%d)", reset_reason_to_str(reason), (int)reason);

    esp_set_cpu_freq(ESP_CPU_FREQ_80M);
    ESP_LOGI(TAG, "CPU frequency set to 80 MHz");

    esp_err_t ret = nvs_flash_init();
    if (ret == ESP_ERR_NVS_NO_FREE_PAGES || ret == ESP_ERR_NVS_NEW_VERSION_FOUND) {
        ESP_ERROR_CHECK(nvs_flash_erase());
        ret = nvs_flash_init();
    }
    ESP_ERROR_CHECK(ret);
    ESP_LOGI(TAG, "NVS initialized");

    int disp_ret = display_init(&display, SDA_PIN, SCL_PIN, SSD1306_I2C_ADDR_0);
    if (disp_ret != 0) {
        ESP_LOGE(TAG, "Display init FAILED");
    }

#if ENS160_ENABLE
    int ens_init_ret = ens160_init(I2C_NUM_0);
    if (ens_init_ret != 0) {
        ESP_LOGE(TAG, "Failed to initialize ENS160");
    }
#else
    int ens_init_ret = -1;
#endif
    int aht_init_ret = aht21_init(I2C_NUM_0);
    if (aht_init_ret != 0) {
        ESP_LOGE(TAG, "Failed to initialize AHT21");
    }

    // Read sensors once to initialize display data
    aht21_data_t aht_data = {0};
    ens160_data_t ens_data = {0};
    if (aht21_read(I2C_NUM_0, &aht_data) == 0) {
        last_aht_data = aht_data;
        int t_int = (int)aht_data.temperature;
        int t_dec = (int)(aht_data.temperature * 10) % 10;
        if (t_dec < 0) t_dec = -t_dec;
        ESP_LOGI(TAG, "Initial sensor read: T=%d.%d H=%d", t_int, t_dec, (int)aht_data.humidity);
    }
#if ENS160_ENABLE
    if (ens160_read(I2C_NUM_0, &ens_data) == 0) {
        last_ens_data = ens_data;
        ESP_LOGI(TAG, "Initial sensor read: CO2=%u TVOC=%u AQI=%u", ens_data.eco2, ens_data.tvoc, ens_data.aqi);
    }
#endif

    button_init();

    if (data_storage_init() != 0) {
        ESP_LOGE(TAG, "Failed to initialize data storage");
    }
    ESP_LOGI(TAG, "Data storage initialized, %d records", data_storage_get_count());

    if (wifi_sync_init(CONFIG_CLIENT_ID) != ESP_OK) {
        ESP_LOGE(TAG, "Failed to initialize WiFi sync");
    }
    
    ESP_LOGI(TAG, "Server discovery: UDP broadcast on port 5000");

    display_font = font_builtin_fonts[FONT_FACE_GLCD5x7];

    display_clear_fb(&display);
    display_draw_string_scaled(&display, display_font, 0, 0, "Client", 2);
    display_draw_string_scaled(&display, display_font, 0, 17, "Ready", 2);
    display_present(&display);
    display_on(&display);

    vTaskDelay(pdMS_TO_TICKS(2000));

    display_clear_fb(&display);
    display_present(&display);
    display_off(&display);

    // Self-test summary
    {
        size_t spiffs_total = 0, spiffs_used = 0;
        esp_err_t spiffs_ret = esp_spiffs_info("storage", &spiffs_total, &spiffs_used);
        int storage_count = data_storage_get_count();
        ESP_LOGI(TAG, "=== SELF-TEST ===");
        ESP_LOGI(TAG, "  NVS: OK");
        ESP_LOGI(TAG, "  I2C: init OK (SDA=GPIO4 SCL=GPIO5)");
        ESP_LOGI(TAG, "  Display: %s", (disp_ret == 0) ? "OK" : "FAILED");
#if ENS160_ENABLE
        ESP_LOGI(TAG, "  ENS160: %s", (ens_init_ret == 0) ? "detected" : "not detected or warming");
#else
        ESP_LOGI(TAG, "  ENS160: disabled (ENS160_ENABLE=0)");
#endif
        ESP_LOGI(TAG, "  AHT21: %s", (aht_init_ret == 0) ? "detected" : "failed");
        ESP_LOGI(TAG, "  SPIFFS: %s (total=%u used=%u)",
                 spiffs_ret == ESP_OK ? "OK" : "FAIL", spiffs_total, spiffs_used);
        ESP_LOGI(TAG, "  Storage: %d records saved", storage_count);
        ESP_LOGI(TAG, "  Client ID: %s", wifi_sync_get_client_id() ? wifi_sync_get_client_id() : CONFIG_CLIENT_ID);
        ESP_LOGI(TAG, "  Primary SSID: %s", CLIENT_WIFI_SSID);
        if (strlen(CLIENT_WIFI_SSID_2) > 0) {
            ESP_LOGI(TAG, "  Secondary SSID: %s", CLIENT_WIFI_SSID_2);
        }
        ESP_LOGI(TAG, "  Time source: %s", (time(NULL) > 0) ? "server" : "none");
        ESP_LOGI(TAG, "  Basic mode: %s", wifi_sync_is_basic_mode() ? "true" : "false");
        ESP_LOGI(TAG, "  Heap at init: %d KB", (int)(esp_get_free_heap_size() / 1024));
        ESP_LOGI(TAG, "=== END SELF-TEST ===");
    }

    // Create client task with 4KB stack
    xTaskCreate(client_task, "client_task", 12288, NULL, 5, &client_task_handle);
    button_set_task_handle(client_task_handle);
    
    ESP_LOGI(TAG, "Client task created");
    
    // app_main done — delete this task (don't idle-loop, known rst cause:2 on ESP8266)
    vTaskDelete(NULL);
}

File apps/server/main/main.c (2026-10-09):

#include <stdio.h>
#include <string.h>
#include <time.h>
#include "freertos/FreeRTOS.h"
#include "freertos/task.h"
#include "esp_log.h"
#include "esp_system.h"
#include "esp_task_wdt.h"
#include "esp_wifi.h"
#include "nvs_flash.h"
#include "nvs.h"
#include "lwip/apps/sntp.h"
#include "lwip/sockets.h"
#include "lwip/netdb.h"
#include "esp_spiffs.h"
#include "tcpip_adapter.h"
#include "wifi_manager.h"
#include "data_store.h"
#include "client_registry.h"
#include "http_server.h"

static const char *TAG = "server";

#define STALE_TIMEOUT_SEC 360
#define MAIN_LOOP_INTERVAL_MS 30000
#define UDP_DISCOVER_PORT 5000
#define DEFAULT_SYNC_INTERVAL_SEC 600
#define DEFAULT_TIMEZONE "WET0WEST,M3.5.0/1,M10.5.0/2"

static uint32_t server_start_tick = 0;
static uint32_t g_sync_interval = DEFAULT_SYNC_INTERVAL_SEC;
static char g_timezone[64] = DEFAULT_TIMEZONE;

uint32_t server_get_timestamp(void) {
    time_t now = time(NULL);
    if (now > 0) return (uint32_t)now;
    return (xTaskGetTickCount() - server_start_tick) * portTICK_PERIOD_MS / 1000;
}

static int read_sta_creds(char *ssid, size_t ssid_sz, char *pass, size_t pass_sz) {
    nvs_handle_t nvs;
    esp_err_t err = nvs_open("wifi", NVS_READONLY, &nvs);
    if (err != ESP_OK) return -1;

    size_t len = ssid_sz;
    err = nvs_get_str(nvs, "sta_ssid", ssid, &len);
    if (err != ESP_OK) { nvs_close(nvs); return -1; }

    len = pass_sz;
    err = nvs_get_str(nvs, "sta_pass", pass, &len);
    nvs_close(nvs);
    return (err == ESP_OK) ? 0 : -1;
}

static const char *get_sta_ssid(void) {
    static char ssid[32] = "";
    static char pass[64] = "";
    if (ssid[0] == '\0') {
        if (read_sta_creds(ssid, sizeof(ssid), pass, sizeof(pass)) != 0) {
            ssid[0] = '\0';
        }
    }
    return ssid[0] ? ssid : NULL;
}

static const char *get_sta_pass(void) {
    static char ssid[32] = "";
    static char pass[64] = "";
    if (ssid[0] == '\0') {
        read_sta_creds(ssid, sizeof(ssid), pass, sizeof(pass));
    }
    return pass;
}

/* Priority: NVS > wifi.env compile definitions > Kconfig defaults */
static const char *get_effective_ssid(void) {
    const char *nvs_ssid = get_sta_ssid();
    if (nvs_ssid && nvs_ssid[0] != '\0') return nvs_ssid;
#ifdef WIFI_SSID
    if (WIFI_SSID[0] != '\0') return WIFI_SSID;
#endif
    return CONFIG_SERVER_STA_SSID;
}

static const char *get_effective_pass(void) {
    const char *nvs_pass = get_sta_pass();
    if (nvs_pass && nvs_pass[0] != '\0') return nvs_pass;
#ifdef WIFI_PASS
    if (WIFI_PASS[0] != '\0') return WIFI_PASS;
#endif
    return CONFIG_SERVER_STA_PASS;
}

/* Secondary SSID/pass. Priority: NVS (wifi:sta_ssid2 / wifi:sta_pass2) >
 * wifi.env (WIFI_SSID_2 / WIFI_PASS_2) > Kconfig (CONFIG_SERVER_BACKUP_*).
 * Returns NULL when no secondary is configured. */
static const char *get_secondary_ssid(void) {
    static char ssid[32] = "";
    static char pass[64] = "";
    static bool loaded = false;
    if (!loaded) {
        loaded = true;
        nvs_handle_t nvs;
        if (nvs_open("wifi", NVS_READONLY, &nvs) == ESP_OK) {
            size_t len = sizeof(ssid);
            if (nvs_get_str(nvs, "sta_ssid2", ssid, &len) == ESP_OK && ssid[0]) {
                len = sizeof(pass);
                nvs_get_str(nvs, "sta_pass2", pass, &len);
            } else {
                ssid[0] = '\0';
            }
            nvs_close(nvs);
        }
    }
    if (ssid[0]) return ssid;
#ifdef WIFI_SSID_2
    if (WIFI_SSID_2[0] != '\0') return WIFI_SSID_2;
#endif
    if (strlen(CONFIG_SERVER_BACKUP_SSID) > 0) return CONFIG_SERVER_BACKUP_SSID;
    return NULL;
}

static const char *get_secondary_pass(void) {
    static char ssid[32] = "";
    static char pass[64] = "";
    static bool loaded = false;
    if (!loaded) {
        loaded = true;
        nvs_handle_t nvs;
        if (nvs_open("wifi", NVS_READONLY, &nvs) == ESP_OK) {
            size_t len = sizeof(ssid);
            if (nvs_get_str(nvs, "sta_ssid2", ssid, &len) == ESP_OK && ssid[0]) {
                len = sizeof(pass);
                nvs_get_str(nvs, "sta_pass2", pass, &len);
            } else {
                ssid[0] = '\0';
            }
            nvs_close(nvs);
        }
    }
    if (ssid[0]) return pass;
#ifdef WIFI_PASS_2
    if (WIFI_PASS_2[0] != '\0') return WIFI_PASS_2;
#endif
    return CONFIG_SERVER_BACKUP_PASS;
}

void __attribute__((unused)) write_sta_creds(const char *ssid, const char *pass) {
    nvs_handle_t nvs;
    if (nvs_open("wifi", NVS_READWRITE, &nvs) != ESP_OK) return;
    nvs_set_str(nvs, "sta_ssid", ssid);
    nvs_set_str(nvs, "sta_pass", pass);
    nvs_commit(nvs);
    nvs_close(nvs);
    ESP_LOGI(TAG, "STA credentials saved to NVS");
}

uint32_t config_get_sync_interval(void) {
    return g_sync_interval;
}

void config_load_sync_interval(void) {
    nvs_handle_t nvs;
    if (nvs_open("config", NVS_READONLY, &nvs) != ESP_OK) {
        g_sync_interval = DEFAULT_SYNC_INTERVAL_SEC;
        return;
    }
    uint32_t value = DEFAULT_SYNC_INTERVAL_SEC;
    esp_err_t err = nvs_get_u32(nvs, "sync_int", &value);
    nvs_close(nvs);
    if (err == ESP_OK && value > 0) {
        g_sync_interval = value;
    } else {
        g_sync_interval = DEFAULT_SYNC_INTERVAL_SEC;
    }
}

void config_save_sync_interval(uint32_t value) {
    if (value == 0) value = DEFAULT_SYNC_INTERVAL_SEC;
    g_sync_interval = value;
    nvs_handle_t nvs;
    if (nvs_open("config", NVS_READWRITE, &nvs) != ESP_OK) return;
    esp_err_t err = nvs_set_u32(nvs, "sync_int", value);
    if (err == ESP_OK) {
        nvs_commit(nvs);
        ESP_LOGI(TAG, "Sync interval saved: %u sec", value);
    }
    nvs_close(nvs);
}

static void apply_timezone(const char *tz) {
    if (!tz || !tz[0]) return;
    setenv("TZ", tz, 1);
    tzset();
    ESP_LOGI(TAG, "Timezone applied: %s", tz);
}

const char *config_get_timezone(void) {
    return g_timezone;
}

void config_load_timezone(void) {
    nvs_handle_t nvs;
    if (nvs_open("config", NVS_READONLY, &nvs) != ESP_OK) {
        strncpy(g_timezone, DEFAULT_TIMEZONE, sizeof(g_timezone) - 1);
        g_timezone[sizeof(g_timezone) - 1] = '\0';
        return;
    }
    size_t len = sizeof(g_timezone);
    esp_err_t err = nvs_get_str(nvs, "timezone", g_timezone, &len);
    nvs_close(nvs);
    if (err != ESP_OK || g_timezone[0] == '\0') {
        strncpy(g_timezone, DEFAULT_TIMEZONE, sizeof(g_timezone) - 1);
        g_timezone[sizeof(g_timezone) - 1] = '\0';
    }
}

void config_save_timezone(const char *tz) {
    if (!tz || !tz[0]) tz = DEFAULT_TIMEZONE;
    strncpy(g_timezone, tz, sizeof(g_timezone) - 1);
    g_timezone[sizeof(g_timezone) - 1] = '\0';
    apply_timezone(g_timezone);
    nvs_handle_t nvs;
    if (nvs_open("config", NVS_READWRITE, &nvs) != ESP_OK) return;
    esp_err_t err = nvs_set_str(nvs, "timezone", g_timezone);
    if (err == ESP_OK) {
        nvs_commit(nvs);
        ESP_LOGI(TAG, "Timezone saved: %s", g_timezone);
    }
    nvs_close(nvs);
}
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

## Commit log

2026-05-24 Working i2c display
2026-05-24 Update AGENTS.md with data about i2c
2026-05-25 Update AGENTS.md and compose.yml for improved USB device management
2026-05-25 feat: Implement client registry and data storage for HTTP server
    - Added client_registry.c and client_registry.h for managing client information.
    - Introduced data_store.c and data_store.h for handling data records associated with clients.
    - Enhanced CMakeLists.txt to include new source files and required components.
    - Developed http_server.c and http_server.h to manage HTTP requests and responses.
    - Created web_ui.h for serving a simple web interface to display client data.
    - Updated main.c to initialize the HTTP server and manage client data.
    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
    [partitions_server.csv]
2026-05-25 docs: Update AGENTS.md and TODO.md for improved project structure and API details feat: Add partitions_client.csv for client application partition configuration
    [partitions_client.csv]
2026-05-25 feat: Implement data storage and synchronization features
    - Added data_storage.c and data_storage.h for managing client data records.
    - Updated main.c to integrate data storage functionality, including appending records and reading unsynced data.
    - Introduced wifi_sync.c and wifi_sync.h for handling WiFi synchronization of unsynced records.
    - Modified CMakeLists.txt to include new source files and required components.
    - Enhanced http_server.c to support new API endpoints for client data upload and retrieval.
    - Updated web_ui.h to reflect changes in API endpoints for fetching client details.
    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
2026-05-25 feat: Enhance client registry and data store with improved timestamp handling and error management
    [main.c]
2026-05-26 feat: Add WiFi configuration options and UDP discovery feature
    - Introduced Kconfig options for primary and backup WiFi SSID and password.
    - Enhanced HTTP server to handle health checks and client data retrieval.
    - Implemented UDP discovery task to broadcast server IP address.
    - Updated web UI to display connection status and error messages.
    - Improved memory management by dynamically allocating client info and data records.
    - Added backup WiFi functionality to switch networks upon connection failure.
    - Refactored JSON response handling for better performance and error handling.
    [main.c]
2026-05-26 feat: Enhance display functionality and update sensor read intervals for improved performance
2026-05-26 feat: Implement SNTP initialization for time synchronization and update display with current time
2026-05-28 feat: Enhance button functionality with ISR handling and wakeup support; update display initialization with I2C probing
2026-07-08 Refactor button handling and debounce logic; add new button state functions
2026-07-09 Add second wifi to config
    [partitions_server.csv]
2026-07-09 Add basic mode functionality for clients
    - Introduced a basic mode setting that allows clients to operate in a simplified mode (temperature and humidity only).
    - Added NVS storage for basic mode state in `wifi_sync.c` and corresponding load/save functions.
    - Updated client registry to manage basic mode states for each client.
    - Implemented HTTP endpoints to get and set the basic mode for clients.
    - Modified the HTTP server to include basic mode information in client responses.
    - Enhanced the web UI to allow users to toggle basic mode and reflect changes in the displayed data.
2026-07-09 feat: Implement client ID management and renaming functionality
    - Added support for saving and loading client IDs to/from NVS in wifi_sync.c.
    - Introduced functions to handle client ID changes, including saving new IDs and checking for changes.
    - Updated client_registry to manage ID mappings, allowing for renaming of clients while preserving data integrity.
    - Enhanced data_store to rename client data files when IDs are changed.
    - Added HTTP endpoints for client ID renaming and deletion in http_server.c.
    - Updated web UI to include client ID management features, allowing users to rename client IDs via the interface.
    - Improved error handling and logging throughout the client ID management pro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
    [data_store.c, main.c]
2026-07-10 feat: Implement auto-generated partition tables and enhance data storage management
    [partitions_client.csv, partitions_server.csv]
2026-07-10 feat: Enhance button handling and debouncing logic for improved responsiveness
2026-10-09 init kicad
    [schema.kicad_pcb, schema.kicad_sch]
2026-10-09 Ver 1
    [schema.kicad_pcb, schema.kicad_sch]
